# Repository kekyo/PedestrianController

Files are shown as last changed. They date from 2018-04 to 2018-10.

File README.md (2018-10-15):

# American pedestrian signal controller on ESP8266

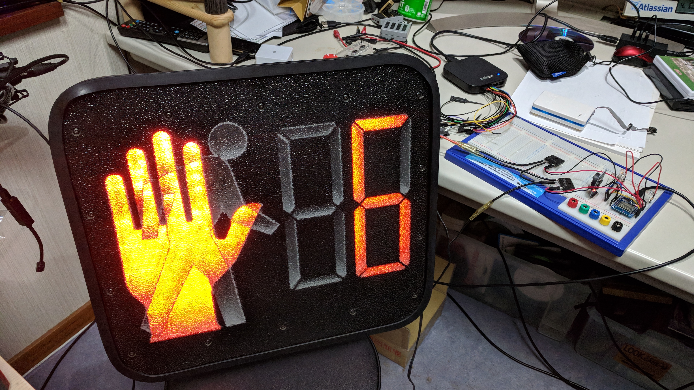
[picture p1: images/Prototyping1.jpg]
Prototyping


## What's this?

* It's pedestrian signal controller running on ESP8266 (aka ESP-WROOM-02).
* I made custom schematic and artwork from scratch.
  * Use EAGLE 8
* I wrote sequencer code by C++ on ESP8266-Arduino IDE.

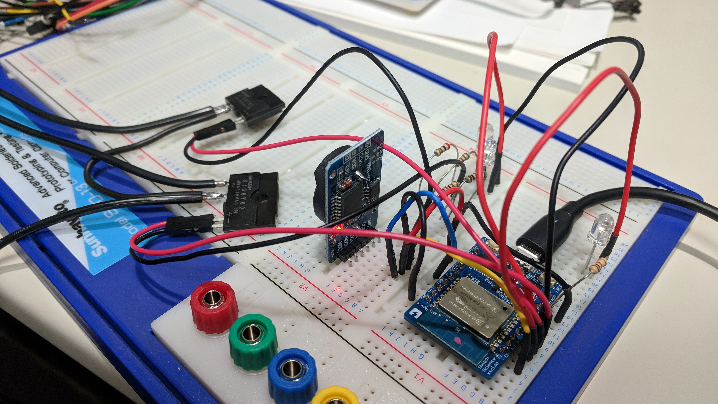
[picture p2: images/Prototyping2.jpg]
Prototyping


### Video

* We record our discussion into YouTube: [Fun with Pedestrian Signal (In japanese)](https://youtu.be/vJiQ18ymqcs)

### NT NAGOYA 2018 conference (2018/10/6)

* We did public and demonstration the MatrixSignalController.
  * It uses with [the ExtremeFeedbackDevice's signal box.](https://github.com/kekyo/ExtremeFeedbackDevice)
  * The three boxes chatting with independent WiFi network, we use http api server and client library.
  * See [the "MatrixSignalController" folder](https://github.com/kekyo/PedestrianController/tree/master/MatrixSignalController) at repository.

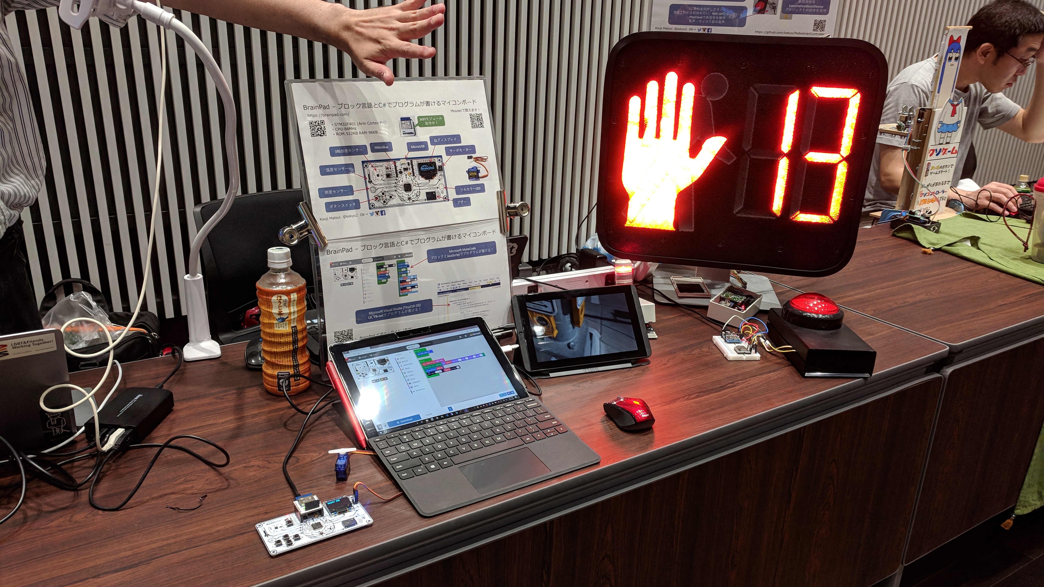
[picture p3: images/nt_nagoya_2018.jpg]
NT NAGOYA 2018


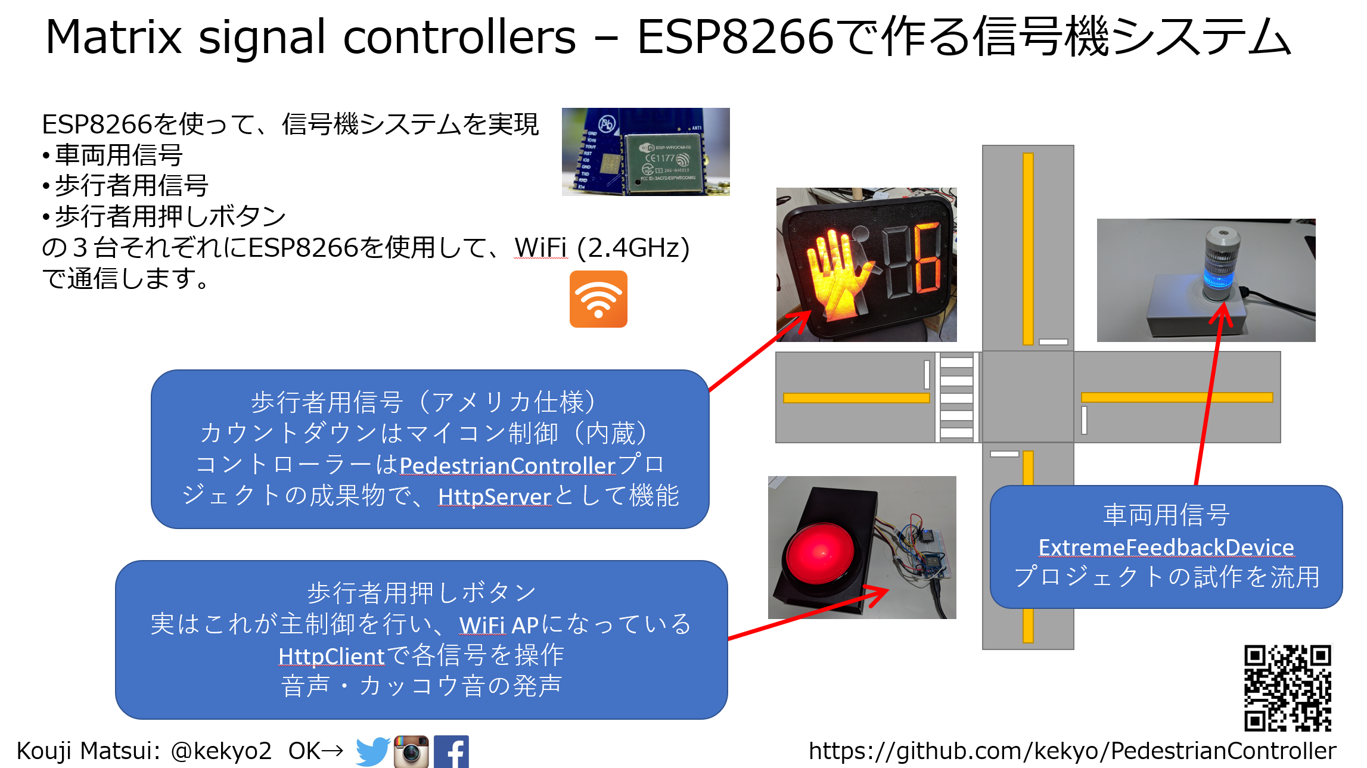
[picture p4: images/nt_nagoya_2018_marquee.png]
NT NAGOYA 2018 marquee (Japanese)


## Features

* Basic sequence for american pedestrian signal standard (3 wired control).
* Scheduled time control between signal-on hour and signal-off hour.
* Battery-backuped RTC using scheduler.
* Auto synchronize NTP server with your WiFi AP.

## Schematic and artwork

* I ordered PCB to [Fusion PCB](https://www.seeedstudio.com/fusion_pcb.html) and finished assemble.

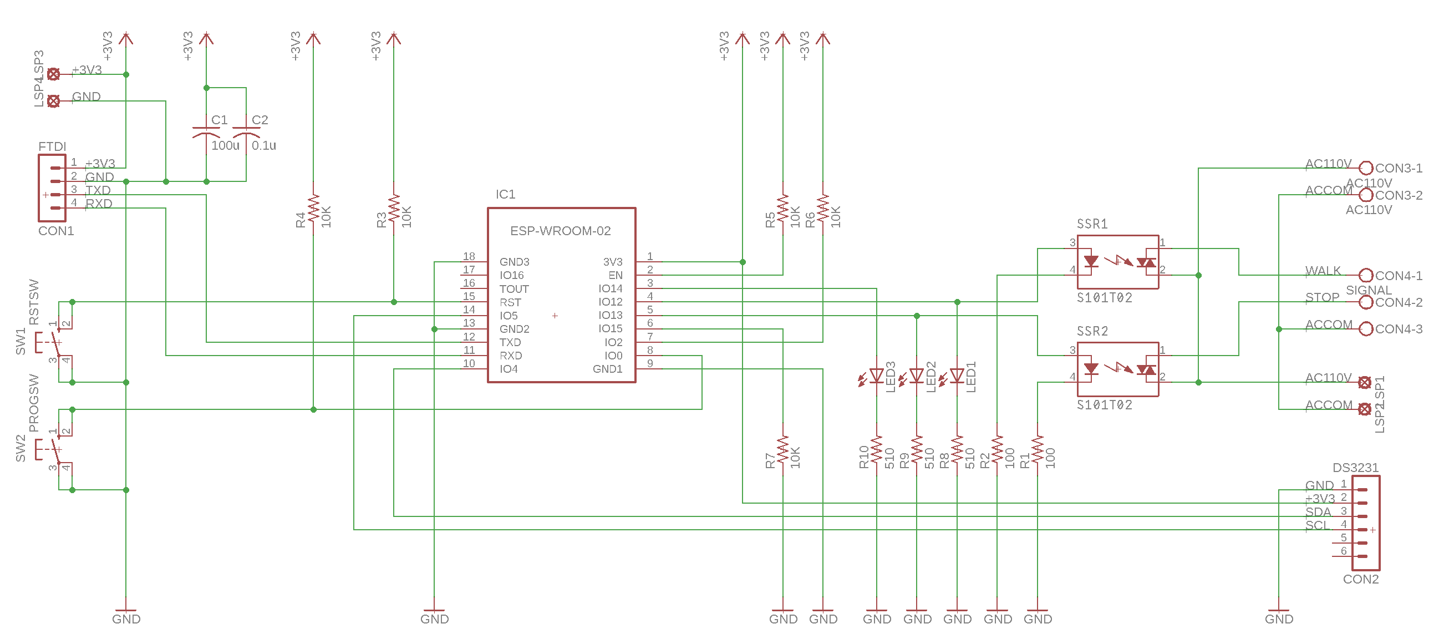
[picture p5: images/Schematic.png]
Schematic


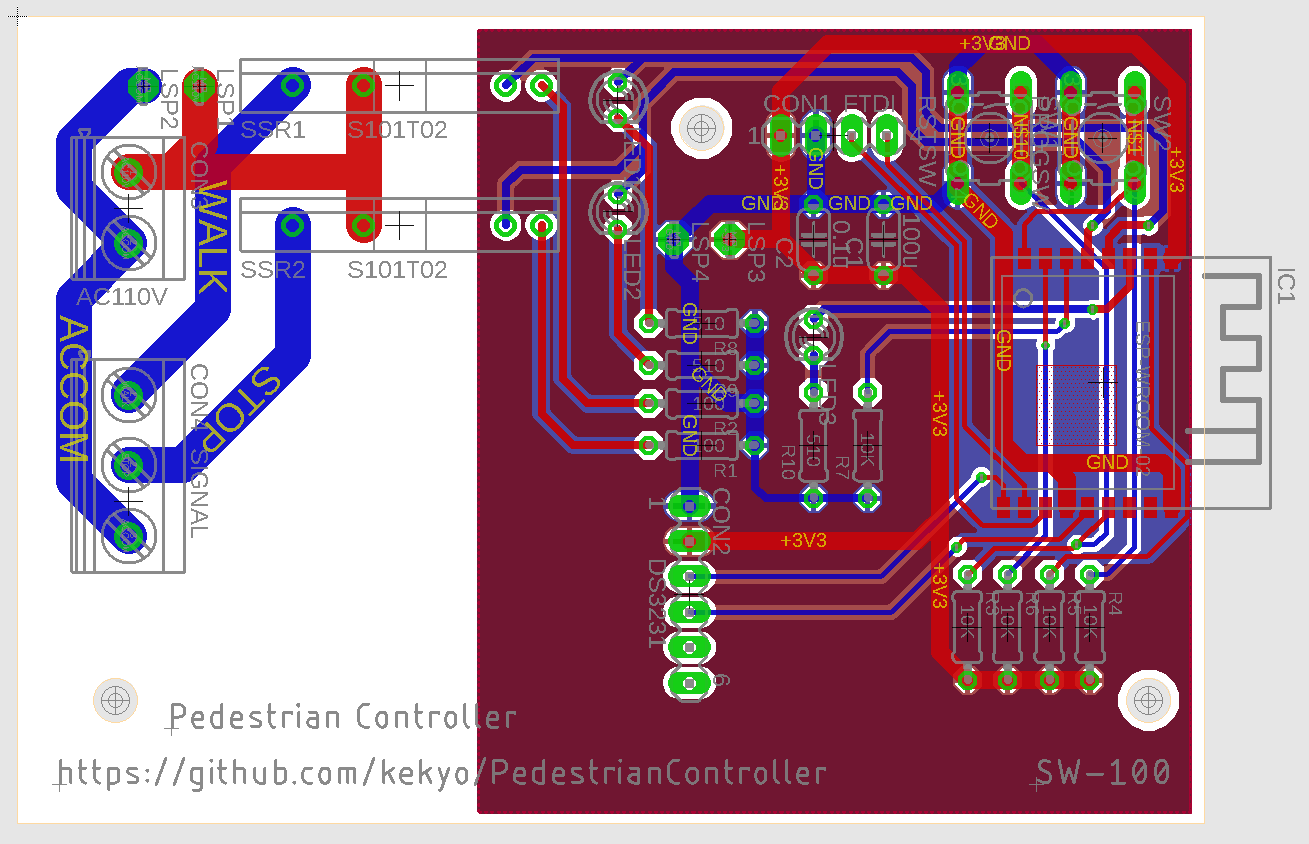
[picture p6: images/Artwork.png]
Artwork


## How to assemble PedestrianController

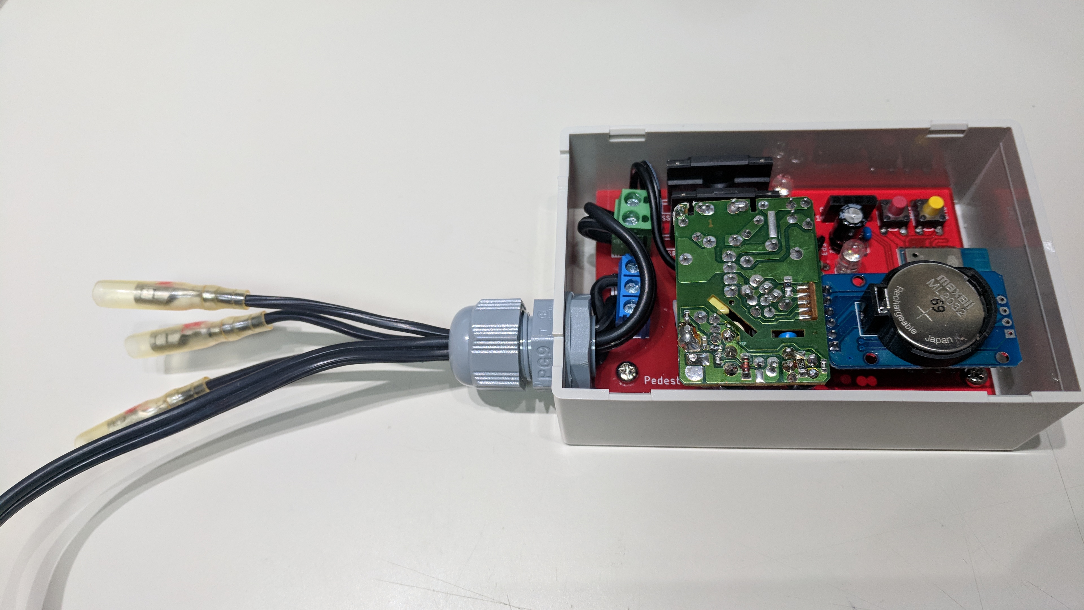
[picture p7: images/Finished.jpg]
Finished


* See also: [How to assemble PedestrianController](HowToAssemble.md)

## License

* Under Apache v2

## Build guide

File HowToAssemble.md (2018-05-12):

# How to assemble PedestrianController.

* This is point for assemble parts from naked plain board.

## Assemble ESP-WROOM-02

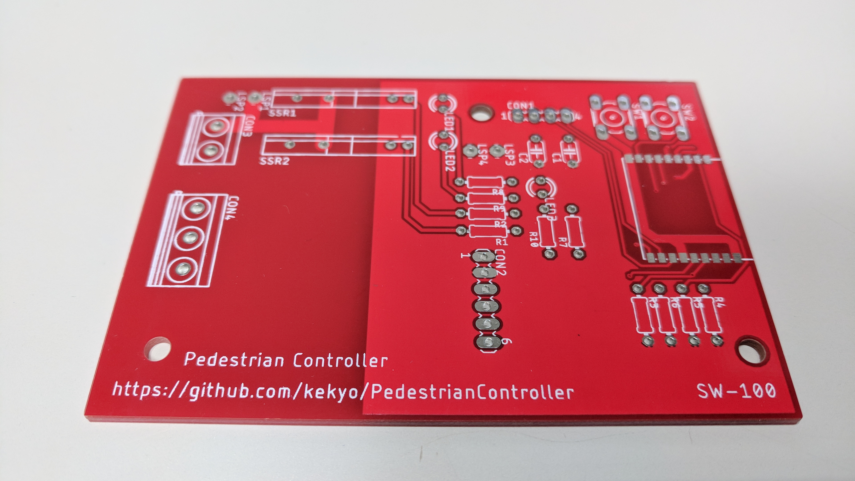
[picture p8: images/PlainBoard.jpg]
PlainBoard


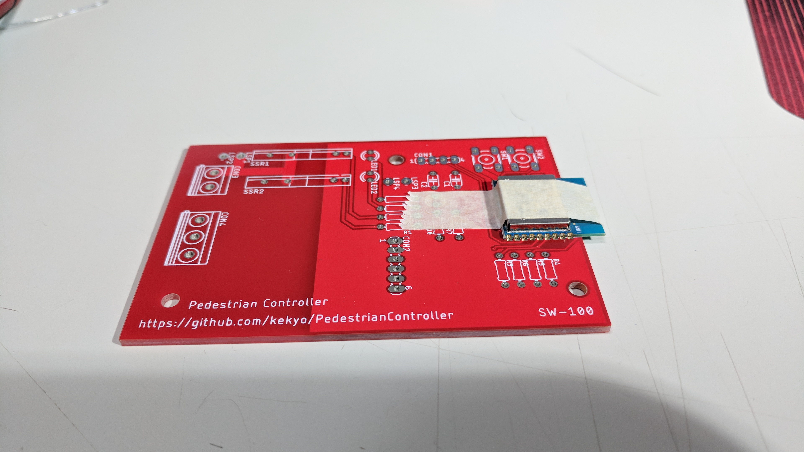
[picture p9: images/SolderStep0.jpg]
SolderStep0


* Light stick ESP-WROOM-02 to board.

FixShifted

* We have to fix shifted position for ESP-WROOM-02 and do solder.

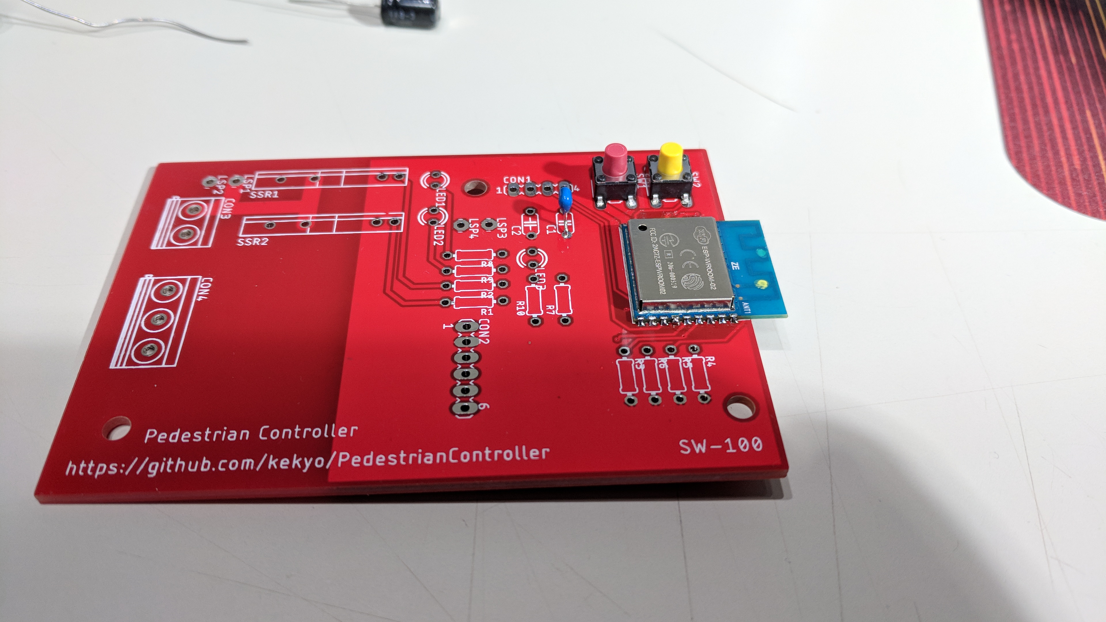
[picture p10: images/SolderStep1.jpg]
SolderStep1


* Mount switches.

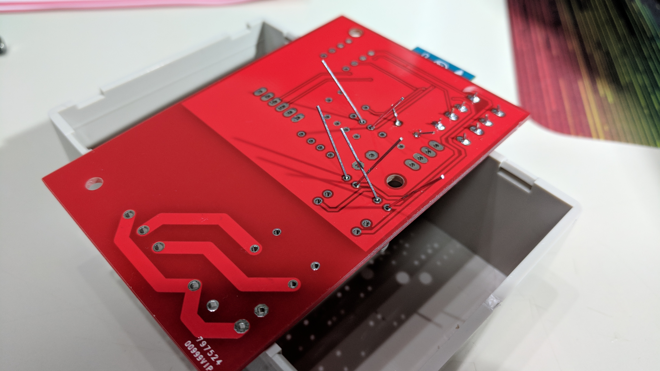
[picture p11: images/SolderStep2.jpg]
SolderStep2


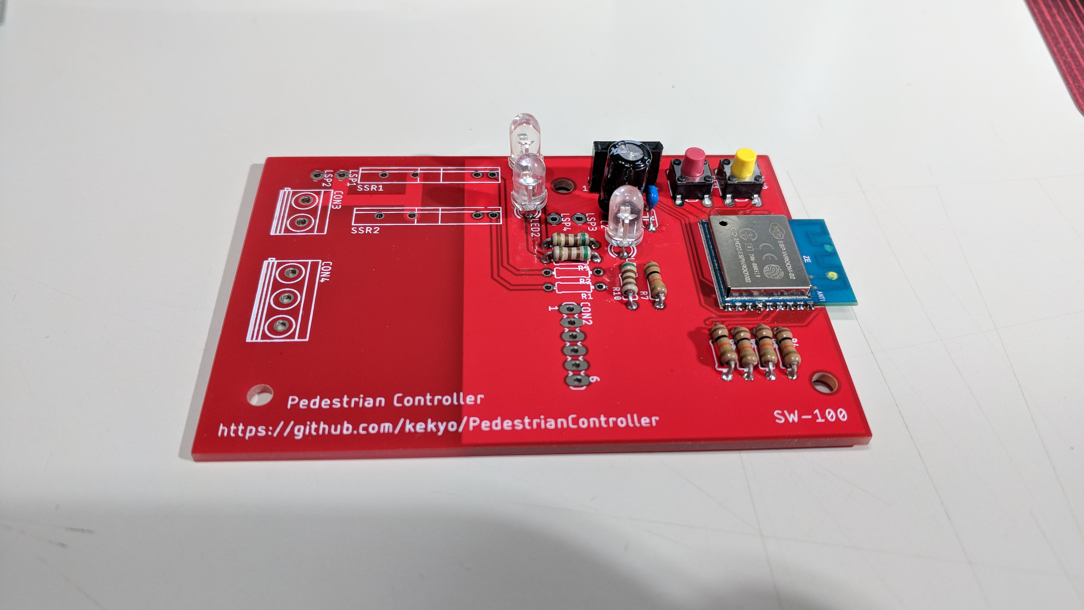
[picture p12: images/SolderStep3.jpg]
SolderStep3


* Finished partial mounting because we have to test before assemble all parts.

## Write PedestrianController firmware.

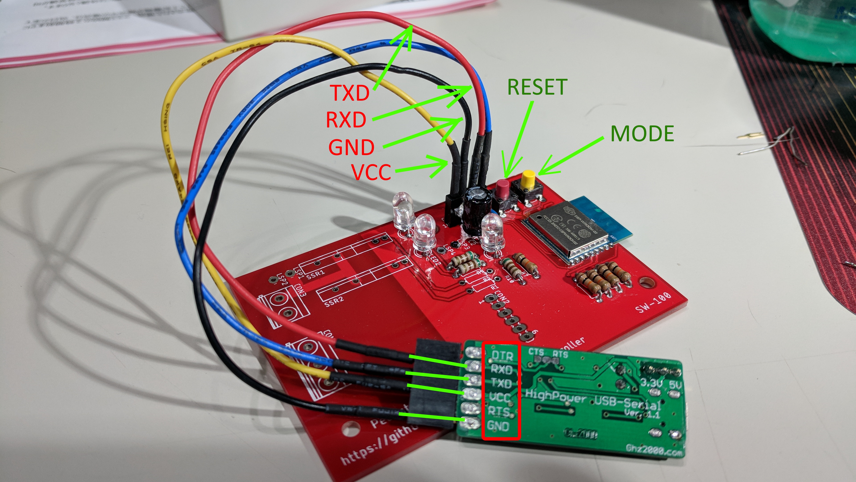
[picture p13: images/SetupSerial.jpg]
SetupSerial


* Connect header "CON1" to USB-serial converter.
  * Caution: We must not mistake power line between 3.3V and GND.
  * I use this converter: [High power USB-Serial converter (In japanese)](https://www.switch-science.com/catalog/3422/)

* Before write, we do power up (Connect serial converter to USB) and reset for firmware-write mode by mounted switches.
  * Swithces-on-off sequence is bit complex.
  * See also the video: https://youtu.be/IjTIz9GXHyo 

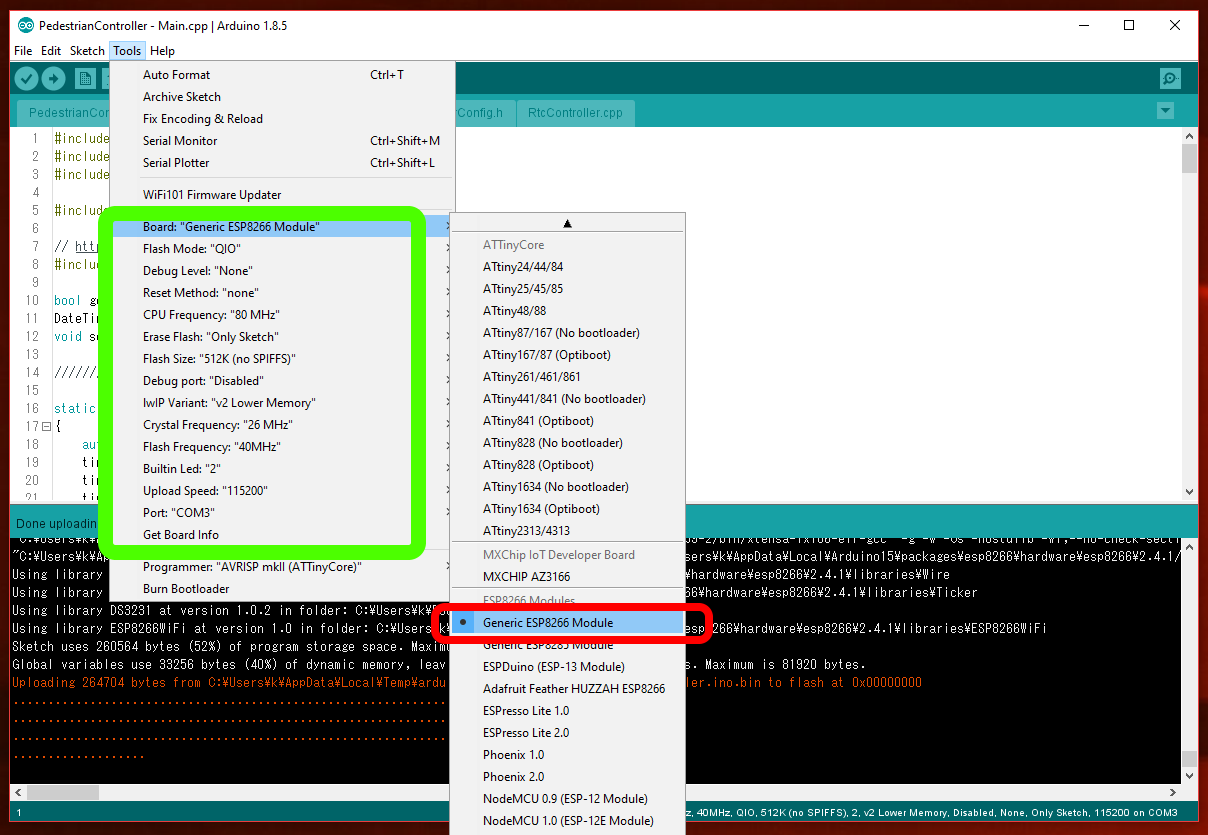
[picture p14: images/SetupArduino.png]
SetupArduino


* Select "Generic ESP8266 Module" at Arduino IDE.
  * And select these menu items (include your USB port "COM?")

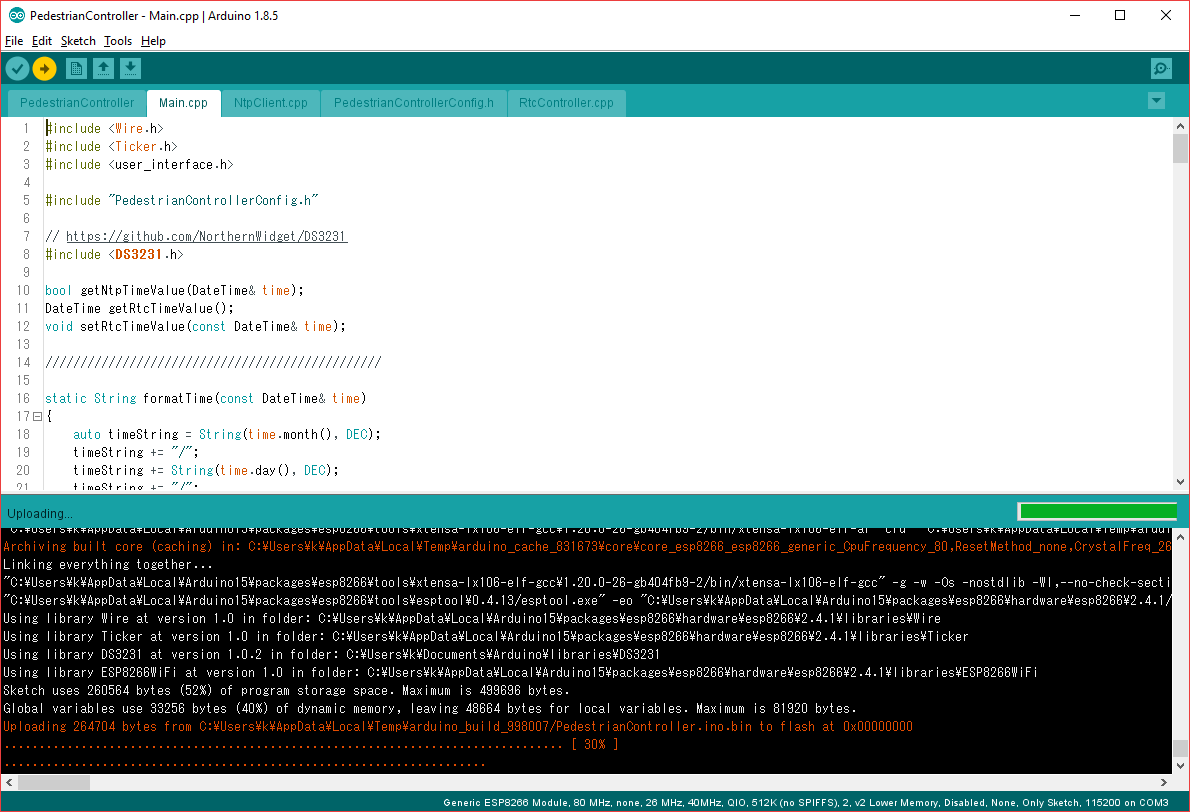
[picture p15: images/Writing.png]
Writing


* This is writing log.
  * After wrote firmware, We can see LED's grow sequence. See also the video: https://youtu.be/FbDNfWrt7zE

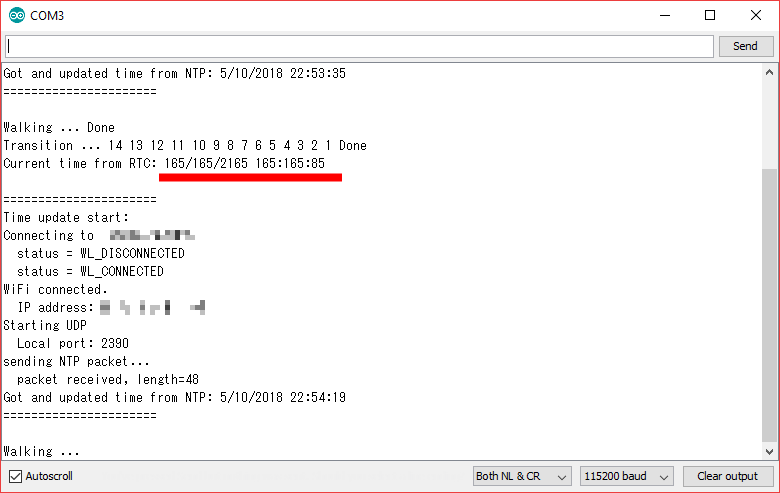
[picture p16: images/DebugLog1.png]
DebugLog1


* And outout debug log. It contains initial wifi sequence.
  * Log contains invalid "Current time from RTC", you can ignore this logs.

## Extract power module from AC power supply unit.

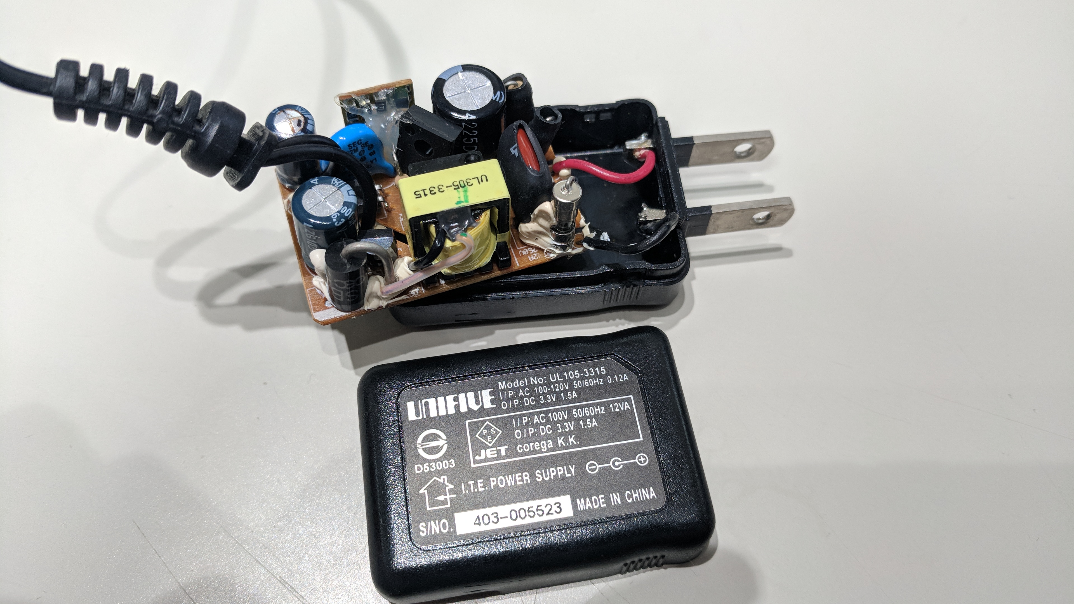
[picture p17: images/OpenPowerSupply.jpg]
OpenPowerSupply


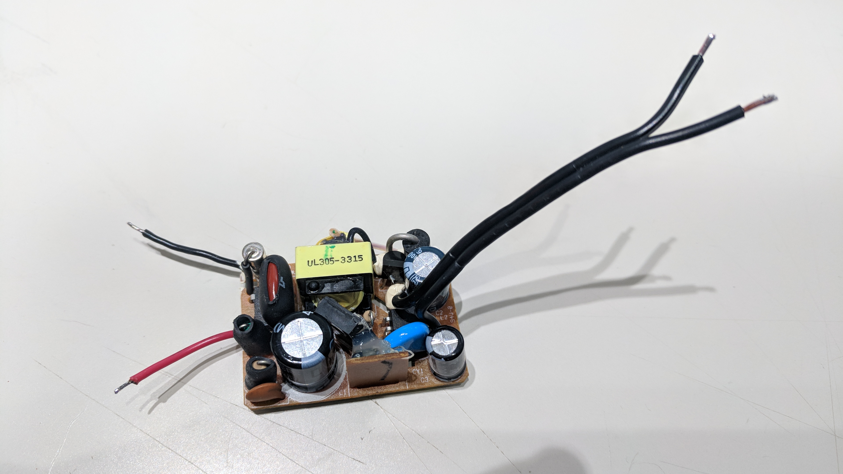
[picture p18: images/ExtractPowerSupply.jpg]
ExtractPowerSupply


## Final assemble steps.

* We have to assemble all parts.
  * Include power terminals (CON3, CON4), SSRs and RTC module header (CON2).

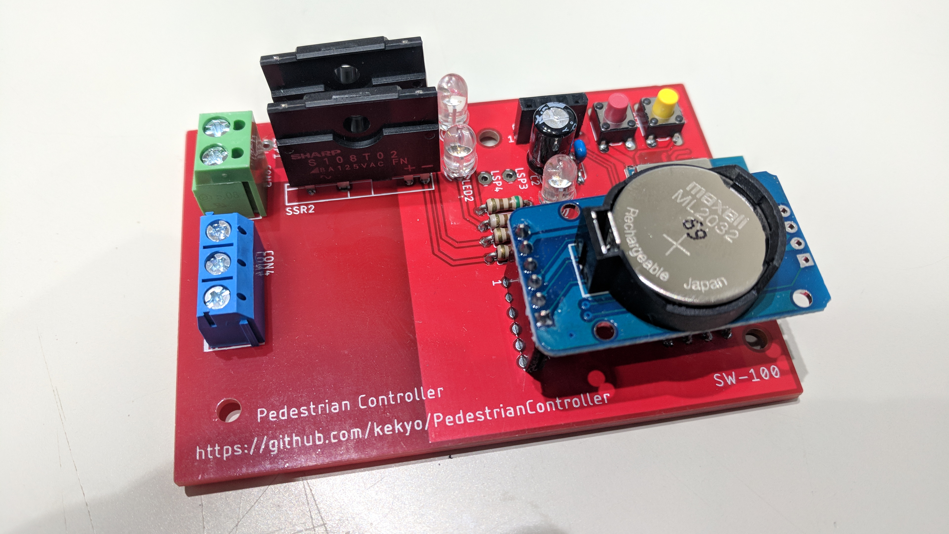
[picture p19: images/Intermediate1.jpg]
Intermediate1


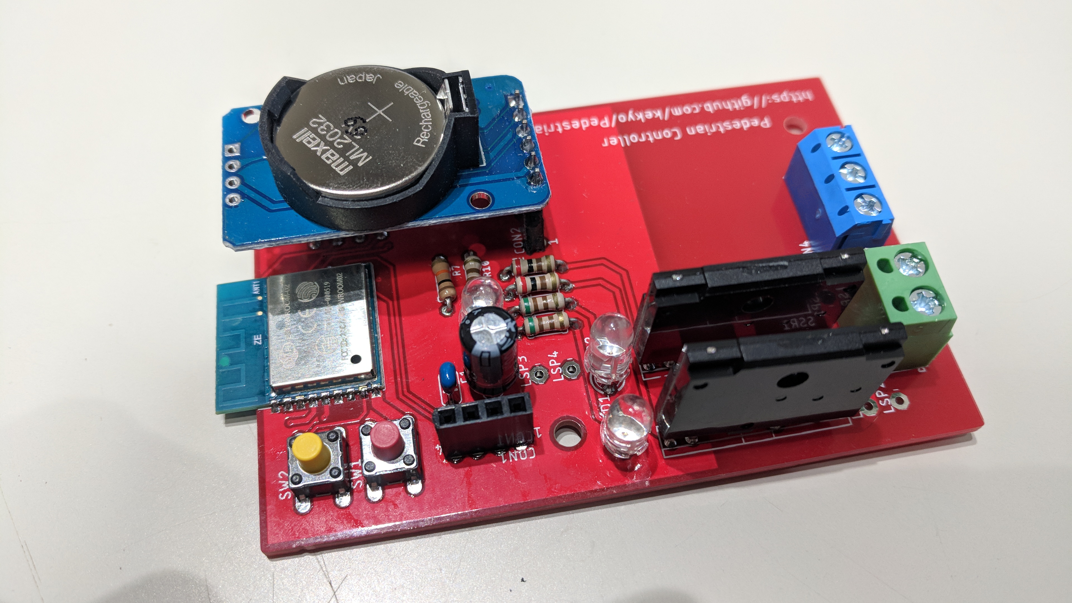
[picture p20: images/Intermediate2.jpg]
Intermediate2


* If RTC module's header pin angled, force straight and insert to header.

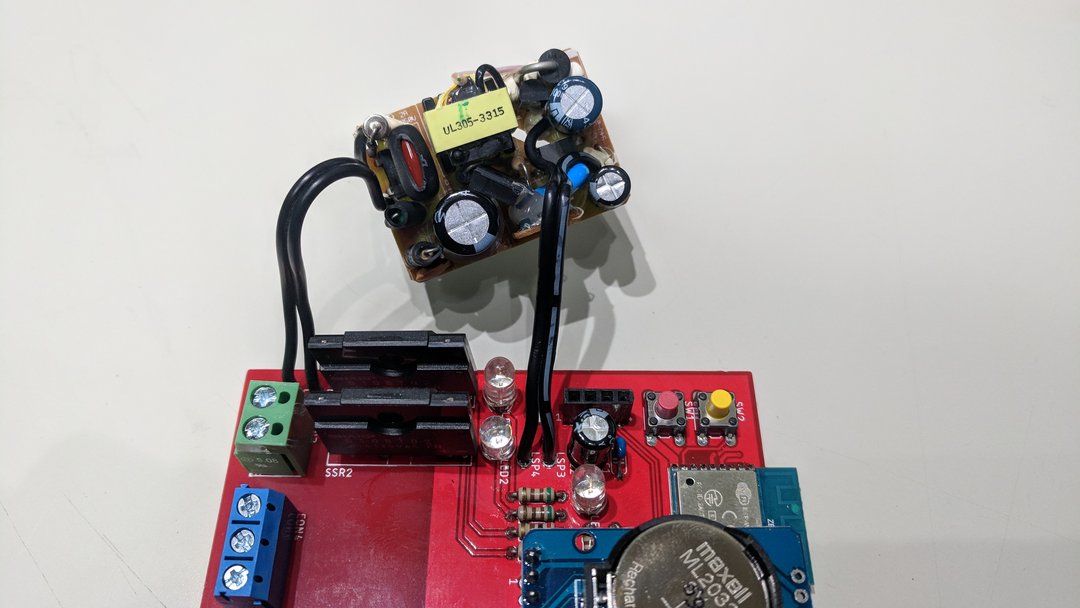
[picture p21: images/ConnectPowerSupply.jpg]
ConnectPowerSupply


* Connect power module onto board.

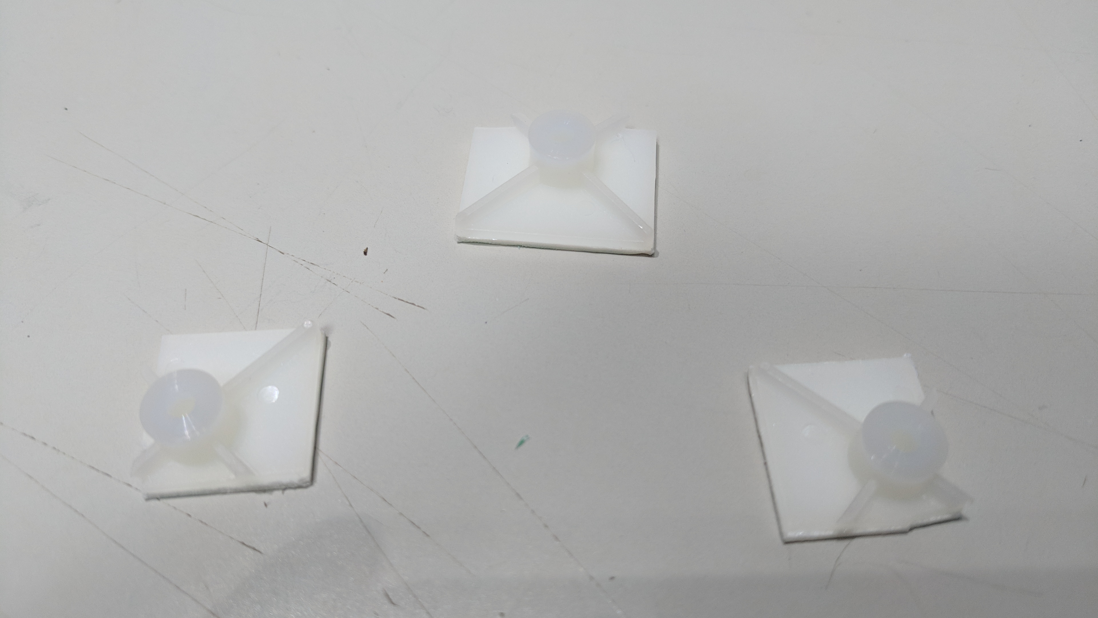
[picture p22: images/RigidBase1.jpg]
RigidBase1


* Cut longer rigid bases.

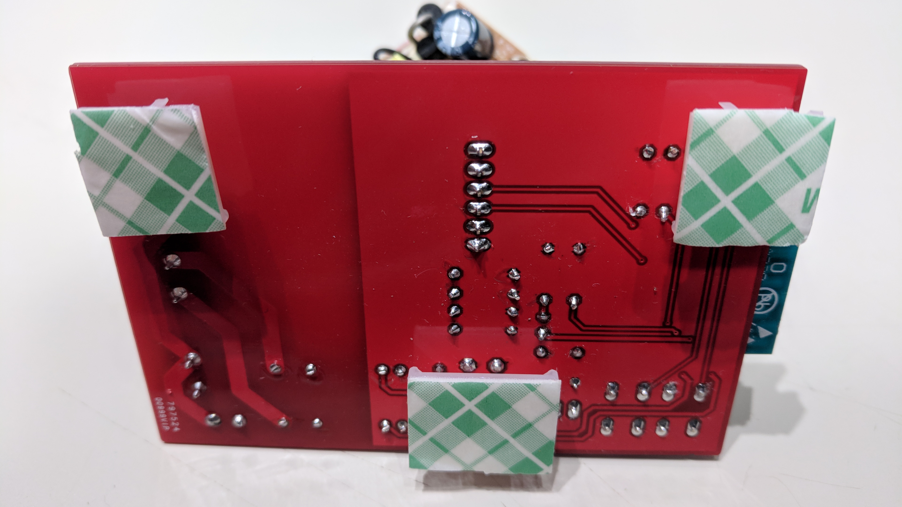
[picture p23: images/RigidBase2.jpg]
RigidBase2


* Pre-mount to board.

Finished

* All items into the box "TAKACHI SW-100."

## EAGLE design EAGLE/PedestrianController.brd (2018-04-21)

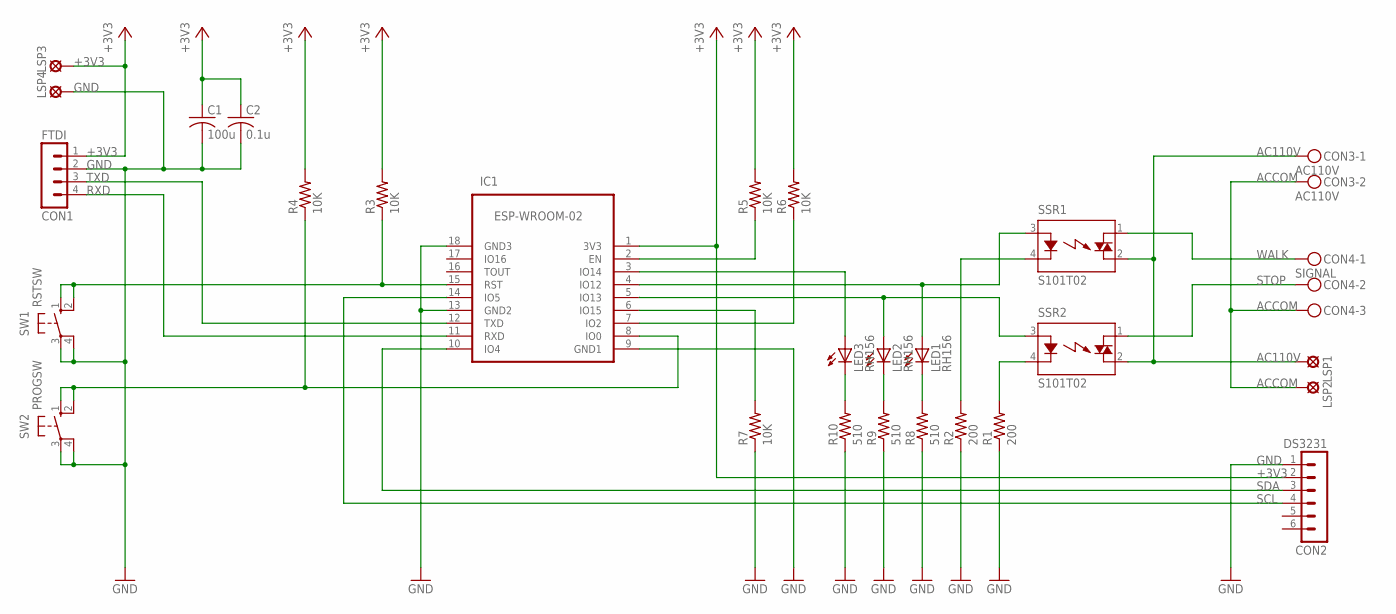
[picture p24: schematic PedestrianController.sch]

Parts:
C1: 100u; C050-024X044
C2: 0.1u; C050-024X044
CON1: FTDI; MA04-1
CON2: DS3231; MA06-1
CON3: AC110V; MKDSN1,5/2-5,08
CON4: SIGNAL; MKDSN1,5/3-5,08
IC1: ESP-WROOM-02; FRONT-FACE
LED1, LED2, LED3: RH156; LED3MM
LSP1, LSP2, LSP3, LSP4: LSP10
R1, R2: 200; 0204/7
R3, R4, R5, R6, R7: 10K; 0204/7
R8, R9, R10: 510; 0204/7
SSR1, SSR2: S101T02; S102T0X
SW1: RSTSW; B3F-10XX
SW2: PROGSW; B3F-10XX

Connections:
+3V3: C1.1, C2.1, CON1.1, CON2.2, IC1.1 (3V3), LSP3.MP, R3.2, R4.2, R5.2, R6.2
AC110V: CON3.1, LSP1.MP, SSR1.2 (DS2), SSR2.2 (DS2)
ACCOM: CON3.2, CON4.3, LSP2.MP
GND: C1.2, C2.2, CON1.2, CON2.1, IC1.9 (GND1), IC1.13 (GND2), IC1.18 (GND3), LSP4.MP, R1.1, R2.1, R7.1, R8.1, R9.1, R10.1, SW1.3, SW1.4 (P1), SW2.3, SW2.4 (P1)
unnamed: IC1.8 (IO0), R4.1, SW2.1 (S), SW2.2 (S1)
unnamed: IC1.5 (IO13), LED2.A, SSR2.3 (A)
unnamed: R2.2, SSR1.4 (K)
unnamed: R1.2, SSR2.4 (K)
unnamed: LED1.K (C), R8.2
unnamed: LED2.K (C), R9.2
unnamed: IC1.3 (IO14), LED3.A
unnamed: IC1.4 (IO12), LED1.A, SSR1.3 (A)
unnamed: IC1.15 (RST), R3.1, SW1.1 (S), SW1.2 (S1)
unnamed: LED3.K (C), R10.2
unnamed: IC1.2 (EN), R5.1
unnamed: IC1.7 (IO2), R6.1
unnamed: IC1.6 (IO15), R7.2
RXD: CON1.4, IC1.11 (RXD)
SCL: CON2.4, IC1.14 (IO5)
SDA: CON2.3, IC1.10 (IO4)
STOP: CON4.2, SSR2.1 (DS1)
TXD: CON1.3, IC1.12 (TXD)
WALK: CON4.1, SSR1.1 (DS1)

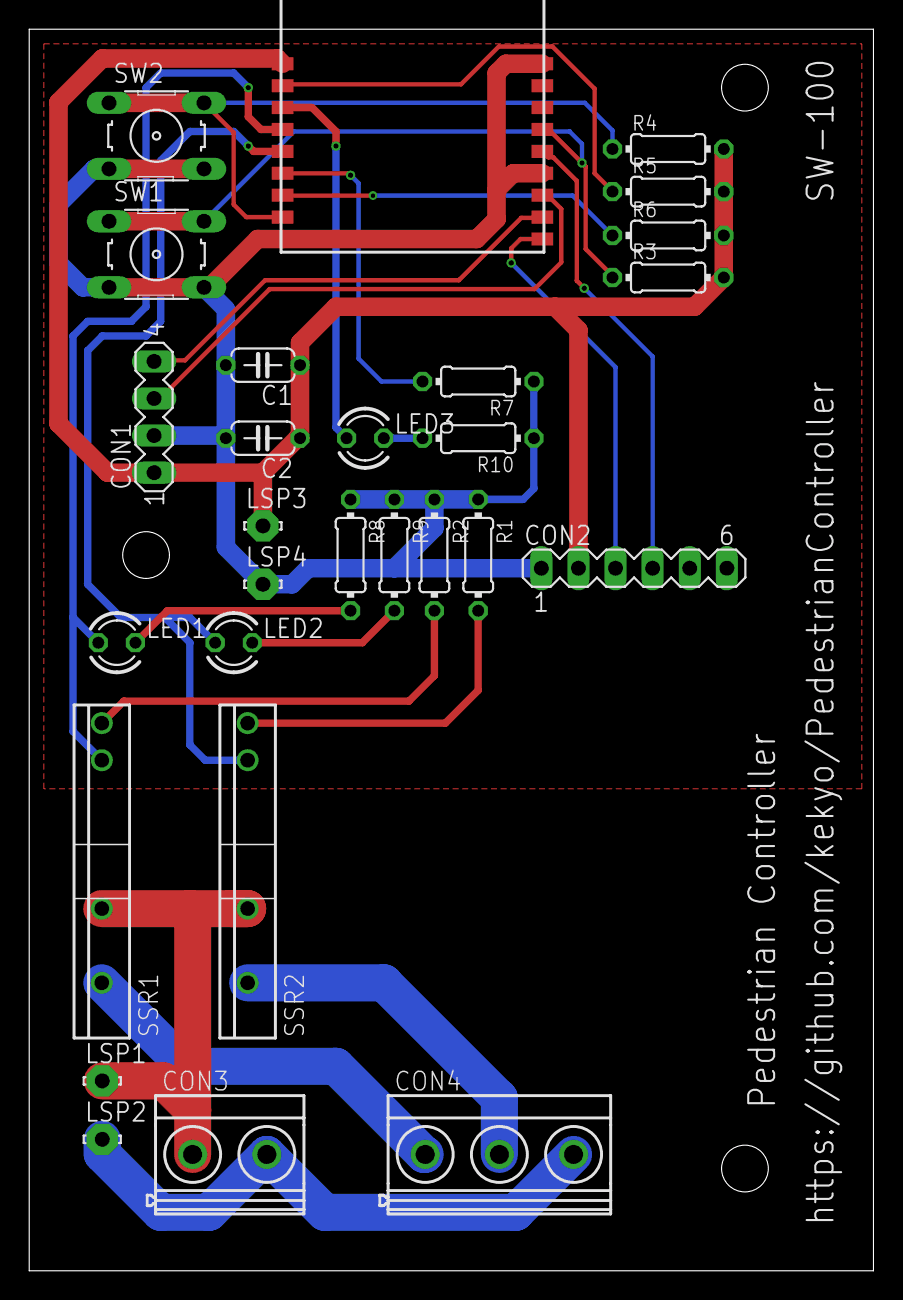
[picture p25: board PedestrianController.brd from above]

Board: 2 copper layers, 57.8 x 85.0 mm, 28 parts (0 on the bottom side), 23 nets.

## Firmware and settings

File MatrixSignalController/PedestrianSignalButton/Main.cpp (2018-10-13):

/////////////////////////////////////////////////////////////////////////////////////////////////
//
// PedestrianController - American pedestrian signal controller on ESP8266
// Copyright (c) 2017-2018 Kouji Matsui (@kozy_kekyo)
//
// PedestrianSignalButton - Matrix signal controller demonstration at NT NAGOYA 2018.
// This is part of PedestrianController.
//
// Licensed under the Apache License, Version 2.0 (the "License");
// you may not use this file except in compliance with the License.
// You may obtain a copy of the License at
//
//	http://www.apache.org/licenses/LICENSE-2.0
//
// Unless required by applicable law or agreed to in writing, software
// distributed under the License is distributed on an "AS IS" BASIS,
// WITHOUT WARRANTIES OR CONDITIONS OF ANY KIND, either express or implied.
// See the License for the specific language governing permissions and
// limitations under the License.
//
/////////////////////////////////////////////////////////////////////////////////////////////////

#include <Wire.h>
#include <ESP8266WiFi.h>
#include <ESP8266WebServer.h>
#include <ESP8266HTTPClient.h>
#include <SoftwareSerial.h>
#include <DFRobotDFPlayerMini.h>    // https://github.com/DFRobot/DFRobotDFPlayerMini
#include <EasyButton.h>             // https://github.com/evert-arias/EasyButton

#include <functional>

#include "Config.h"

////////////////////////////////////////////////

class PedestrianSignalButton
{
private:
    DFRobotDFPlayerMini* pPlayer;
    EasyButton requestButton;

    uint32_t lastTickCount;
    uint32_t delayCount;
    uint32_t cuckooCount;
    uint32_t demoCount;

    enum States
    {
        Waiting1,
        Waiting2,
        WillWalk,
        Walking1,
        Walking2,
        WillWait,
        Waiting0
    } currentState;

    enum RoadSignalStates
    {
        Unknown_Road,
        Stopped_Road,
        Going,
        WillStop
    };

    enum PedestrianSignalStates
    {
        Unknown_Pedestrian,
        Stopped_Pedestrian,
        Walking_Pedestrian,
        Blinking
    };

    bool sendTo(const char* pHost, int port, bool isPost, const char* pResourcePath, String& result)
    {
        String url("http://");
        url += pHost;
        url += ":";
        url += port;
        url += pResourcePath;

        HTTPClient client;
        if (!client.begin(url))
        {
            Serial.println(" failed.");
            return false;
        }

        const auto statusCode = isPost ? client.POST("") : client.GET();
        result = client.getString();

        if (statusCode >= 400)
        {
            Serial.print(" failed:");
        }
        else
        {
            Serial.print(" success:");
        }

        Serial.print(statusCode);
        Serial.print(" [");
        Serial.print(result.c_str());
        Serial.println("].");

        return statusCode < 400;
    }

    bool sendStopToRoadSignal()
    {
        Serial.print("Send 'Stop' to RoadSignal ...");

        String result;
        return sendTo(WIFI_ROAD_SIGNAL_NAME, 80, false, "/api/stop", result);
    }

    bool sendGoToRoadSignal()
    {
        Serial.print("Send 'Go' to RoadSignal ...");

        String result;
        return sendTo(WIFI_ROAD_SIGNAL_NAME, 80, false, "/api/go", result);
    }

    RoadSignalStates getRoadSignal()
    {
        Serial.print("Getting RoadSignal status ...");

        String result;
        if (!sendTo(WIFI_ROAD_SIGNAL_NAME, 80, false, "/api/status", result))
        {
            return RoadSignalStates::Unknown_Road;
        }

        if (result == "Stopped")
        {
            return RoadSignalStates::Stopped_Road;
        }
        if (result == "Going")
        {
            return RoadSignalStates::Going;
        }
        if (result.startsWith("WillStop "))
        {
            return RoadSignalStates::WillStop;
        }

        return RoadSignalStates::Unknown_Road;
    }

    bool sendWalkToPedestrianSignal()
    {
        Serial.print("Send 'Walk' to PedestrianSignal ...");

        String result;
        return sendTo(WIFI_PEDESTRIAN_SIGNAL_NAME, 80, false, "/api/walk", result);
    }

    bool sendStopToPedestrianSignal()
    {
        Serial.print("Send 'Stop' to PedestrianSignal ...");

        String result;
        return sendTo(WIFI_PEDESTRIAN_SIGNAL_NAME, 80, false, "/api/stop", result);
    }

    PedestrianSignalStates getPedestrianSignal()
    {
        Serial.print("Getting PedestrianSignal status ...");

        String result;
        if (!sendTo(WIFI_PEDESTRIAN_SIGNAL_NAME, 80, false, "/api/status", result))
        {
            return PedestrianSignalStates::Unknown_Pedestrian;
        }

        if (result == "Stopped")
        {
            return PedestrianSignalStates::Stopped_Pedestrian;
        }
        if (result == "Going")
        {
            return PedestrianSignalStates::Walking_Pedestrian;
        }
        if (result.startsWith("Blinking "))
        {
            return PedestrianSignalStates::Blinking;
        }

        return PedestrianSignalStates::Unknown_Pedestrian;
    }

    void requested()
    {
        switch (currentState)
        {
            case States::Waiting1:
                digitalWrite(PUMPED, HIGH);
                delayCount = millis();
                currentState = States::Waiting2;
                pPlayer->play(WAIT_SOUND);
                delay(300);
                break;

            // Fall through
            case States::Waiting2:
                pPlayer->play(WAIT_SOUND);
                delay(300);
                break;
        }
    }

    void tick()
    {
        switch (currentState)
        {
            case States::Waiting1:
                demoCount--;
                if (demoCount == 0)
                {
                    digitalWrite(PUMPED, HIGH);
                    delayCount = millis();
                    currentState = States::Waiting2;
                    pPlayer->play(WAIT_SOUND);
                    delay(300);
                }
                break;

            case States::Waiting2:
                {
                    const auto now = millis();
                    if ((now - delayCount) >= (TRANSITION_WAITING2 * 1000))
                    {
                        sendStopToRoadSignal();
                        currentState = States::WillWalk;
                    }
                }
                break;

            case States::WillWalk:
                if (getRoadSignal() == RoadSignalStates::Stopped_Road)
                {
                    digitalWrite(PUMPED, LOW);
                    sendWalkToPedestrianSignal();
                    delayCount = millis();
                    currentState = States::Walking1;
                }
                break;

            case States::Walking1:
                {
                    const auto now = millis();
                    if ((now - delayCount) >= (TRANSITION_WALKING * 1000))
                    {
                        sendStopToPedestrianSignal();
                        currentState = States::WillWait;
                    }
                    else
                    {
                        cuckooCount = millis();
                        currentState = States::Walking2;
                    }
                }
                break;

            case States::Walking2:
                {
                    const auto now = millis();
                    if ((now - cuckooCount) >= 1000)
                    {
                        pPlayer->play(CUCKOO_SOUND);
                        currentState = States::Walking1;
                    }
                }
                break;

            case States::WillWait:
                if (getPedestrianSignal() == PedestrianSignalStates::Stopped_Pedestrian)
                {
                    delayCount = millis();
                    currentState = States::Waiting0;
                }
                break;

            case States::Waiting0:
                {
                    const auto now = millis();
                    if ((now - delayCount) >= (TRANSITION_WAITING0 * 1000))
                    {
                        sendGoToRoadSignal();
                        demoCount = TRANSITION_DEMO;
                        currentState = States::Waiting1;
                    }
                }
                break;
        }
    }

public:
    PedestrianSignalButton()
        : pPlayer(nullptr), currentState(States::Waiting1), requestButton(REQUEST)
        , lastTickCount(0), delayCount(0), cuckooCount(0), demoCount(TRANSITION_DEMO)
    {
    }

    void Init(DFRobotDFPlayerMini* pPlayer)
    {
        this->pPlayer = pPlayer;

        while (!sendGoToRoadSignal());
        while (!sendStopToPedestrianSignal());

        requestButton.onPressed([&]() { requested(); });
        requestButton.begin();
    }

    void handle()
    {
        requestButton.read();

        const auto now = millis();
        if ((now - lastTickCount) >= 1000)
        {
            lastTickCount = now;
            tick();
        }
    }
};

////////////////////////////////////////////////

SoftwareSerial softwareSerial(DFPLAYER_RX, DFPLAYER_TX);
DFRobotDFPlayerMini player;

PedestrianSignalButton button;

void setup(void)
{
    Serial.begin(115200);
    softwareSerial.begin(9600);
    Wire.begin();

    pinMode(PUMPED, OUTPUT);

    delay(100);

    digitalWrite(PUMPED, LOW);

    delay(500);

    Serial.println("    ");
    Serial.println("PedestrianSignalButton start.");

    Serial.print("Initializing DFPlayer ");
    while (true)
    {
        Serial.print(".");
        if (!player.begin(softwareSerial))
        {
            delay(500);
        }
        else
        {
            player.volume(30);
            break;
        }
    }
    Serial.println(" done.");

    const auto localIP = IPAddress(192, 168, 4, 1);
    const auto gateway = IPAddress(192, 168, 4, 1);
    const auto netmask = IPAddress(255, 255, 255, 0);

    WiFi.mode(WIFI_AP);
    WiFi.softAPConfig(localIP, gateway, netmask);
    WiFi.softAP(WIFI_SSID, WIFI_PASSWORD);

    Serial.print("Served WiFi [");
    Serial.print(WIFI_SSID);
    Serial.print("] ");

    Serial.println("");
    Serial.print("Connected [");
    Serial.print(WiFi.softAPIP());
    Serial.println("]");

    button.Init(&player);
}

void loop(void)
{
    button.handle();
}

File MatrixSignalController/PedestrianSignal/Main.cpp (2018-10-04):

/////////////////////////////////////////////////////////////////////////////////////////////////
//
// PedestrianController - American pedestrian signal controller on ESP8266
// Copyright (c) 2017-2018 Kouji Matsui (@kozy_kekyo)
//
// PedestrianSignal - Matrix signal controller demonstration at NT NAGOYA 2018.
// This is part of PedestrianController.
//
// Licensed under the Apache License, Version 2.0 (the "License");
// you may not use this file except in compliance with the License.
// You may obtain a copy of the License at
//
//	http://www.apache.org/licenses/LICENSE-2.0
//
// Unless required by applicable law or agreed to in writing, software
// distributed under the License is distributed on an "AS IS" BASIS,
// WITHOUT WARRANTIES OR CONDITIONS OF ANY KIND, either express or implied.
// See the License for the specific language governing permissions and
// limitations under the License.
//
/////////////////////////////////////////////////////////////////////////////////////////////////

#include <Wire.h>
#include <ESP8266WiFi.h>
#include <ESP8266WebServer.h>
#include <Ticker.h>

#include <functional>

#include "Config.h"

////////////////////////////////////////////////

class PedestrianSignalController
{
private:
    ESP8266WebServer* pServer;
    HardwareSerial* pSerial;

    Ticker ticker;

    volatile bool tickStatus;
    volatile uint8_t blinkingRemains;

    enum States
    {
        Stopped,
        Walking,
        BlinkOn,
        BlinkOff
    } volatile currentState;

    enum RequestStates
    {
        None,
        Stop,
        Walk
    } volatile requestState;

    void requestStatus()
    {
        String result;
        switch (currentState)
        {
            case States::Stopped:
                result = "Stopped";
                break;
            case States::Walking:
                result = "Walking";
                break;
            case States::BlinkOn:
            case States::BlinkOff:
                result = "Blinking ";
                result += blinkingRemains;
                break;
        }

        pServer->send(200, "text/plain", result.c_str());
    }

    void requestWalk()
    {
        requestState = RequestStates::Walk;
        pServer->send(200, "text/plain", "Walk requested.");
        pSerial->println("Walk requested.");
    }

    void requestStop()
    {
        requestState = RequestStates::Stop;
        pServer->send(200, "text/plain", "Stop requested.");
        pSerial->println("Stop requested.");
    }

    void requestNotFound()
    {
        pServer->send(404, "text/plain", "Invalid resource path.");
    }

    void tick()
    {
        switch (currentState)
        {
            case States::Stopped:
                switch (requestState)
                {
                    case RequestStates::Stop:
                        requestState = None;
                        break;
                    case RequestStates::Walk:
                        digitalWrite(STOP, LOW);
                        digitalWrite(WALK, HIGH);
                        currentState = States::Walking;
                        requestState = None;
                        break;
                    default:
                        break;
                }
                break;
            case States::Walking:
                switch (requestState)
                {
                    case RequestStates::Stop:
                        digitalWrite(WALK, LOW);
                        digitalWrite(STOP, HIGH);
                        blinkingRemains = TRANSITION_COUNT;
                        currentState = States::BlinkOff;
                        requestState = None;
                       break;
                    case RequestStates::Walk:
                        requestState = None;
                        break;
                    default:
                        break;
                }
                break;
            case States::BlinkOff:
                digitalWrite(STOP, LOW);
                currentState = States::BlinkOn;
                break;
            case States::BlinkOn:
                digitalWrite(STOP, HIGH);
                blinkingRemains--;
                if (blinkingRemains == 0)
                {
                    currentState = States::Stopped;
                }
                else
                {
                    currentState = States::BlinkOff;
                }
                break;
        }

        digitalWrite(STATUS, tickStatus ? HIGH : LOW);
        tickStatus = !tickStatus;
    }

    static void tickHandler(PedestrianSignalController* pThis)
    {
        pThis->tick();
    }

public:
    PedestrianSignalController()
        : pServer(nullptr), pSerial(nullptr), tickStatus(false)
        , currentState(States::Stopped), blinkingRemains(0), requestState(RequestStates::None)
    {
    }

    void Init(ESP8266WebServer* pServer, HardwareSerial* pSerial)
    {
        this->pServer = pServer;
        this->pSerial = pSerial;

        pinMode(WALK, OUTPUT);
        pinMode(STOP, OUTPUT);
        pinMode(STATUS, OUTPUT);

        delay(100);

        digitalWrite(WALK, LOW);
        digitalWrite(STOP, HIGH);
        digitalWrite(STATUS, LOW);

        pServer->on("/api/status", HTTP_GET, [&]() { requestStatus(); });
        pServer->on("/api/walk", HTTP_GET, [&]() { requestWalk(); });
        pServer->on("/api/stop", HTTP_GET, [&]() { requestStop(); });
        pServer->onNotFound([&]() { requestNotFound(); });

        ticker.attach_ms(TRANSITION_TIME, tickHandler, this);
    }
};

////////////////////////////////////////////////

ESP8266WebServer server(80);

PedestrianSignalController controller;

void setup(void)
{
    Serial.begin(115200);
    Wire.begin();

    delay(500);

    Serial.println("    ");
    Serial.println("PedestrianSignal start.");

    const auto localIP = IPAddress(192, 168, 4, 3);
    const auto gatewayIP = IPAddress(192, 168, 4, 1);
    const auto netmask = IPAddress(255, 255, 255, 0);

    WiFi.mode(WIFI_STA);
    WiFi.config(localIP, gatewayIP, netmask);
    WiFi.setAutoReconnect(true);
    WiFi.begin(WIFI_SSID, WIFI_PASSWORD);

    Serial.print("Connecting WiFi [");
    Serial.print(WIFI_SSID);
    Serial.print("] ");

    while (WiFi.status() != WL_CONNECTED)
    {
        delay(500);
        Serial.print(".");
    }

    Serial.println("");
    Serial.print("Connected [");
    Serial.print(WiFi.localIP());
    Serial.println("]");

    controller.Init(&server, &Serial);
    server.begin();

    Serial.println("HTTP server started.");
}

void loop(void)
{
    server.handleClient();
}

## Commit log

2018-04-17 Fixed cut off procedure for WiFi power.
    [NtpClient.cpp]
2018-04-17 Fixed not calculates local time.
    [NtpClient.cpp]
2018-04-18 Add EAGLE project folder.
    Add EAGLE projects.
    [PedestrianController.sch]
2018-04-18 Finished schematics.
    [PedestrianController.sch]
2018-04-18 Placed parts into board.
    [PedestrianController.brd, PedestrianController.sch]
2018-04-18 Rearranged parts.
    [PedestrianController.brd, PedestrianController.sch]
2018-04-18 Rerouted with broad rule.
    [PedestrianController.brd]
2018-04-18 Rearrange parts, add leds.
    [PedestrianController.brd, PedestrianController.sch]
2018-04-18 Fixed timing for updating RTC.
    [Main.cpp]
2018-04-19 Add status LEDs.
    * Improvement
    [PedestrianController.brd, PedestrianController.sch]
2018-04-19 Rearrange wires.
    [PedestrianController.brd, PedestrianController.sch]
2018-04-19 Add ground pattern.
    [PedestrianController.brd]
2018-04-20 First ordered PCB data.
    [PedestrianController.GBL, PedestrianController.GBO, PedestrianController.GBP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]
2018-04-21 Adjust resistor values by GPIO current specs.
    [PedestrianController.brd, PedestrianController.sch]
2018-04-22 Changed LED blink sequence.
2018-04-22 Fixed calculating next time.
    [Main.cpp]
2018-05-12 Add assembly document.
2018-10-08 Retry fetching current time from ntp server if first time approach.
